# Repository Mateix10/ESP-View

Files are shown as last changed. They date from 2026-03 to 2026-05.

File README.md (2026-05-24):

# ESP-View
This is a music visualiser + DAC that does exactly that - it plays the music through USB, and visualises it.

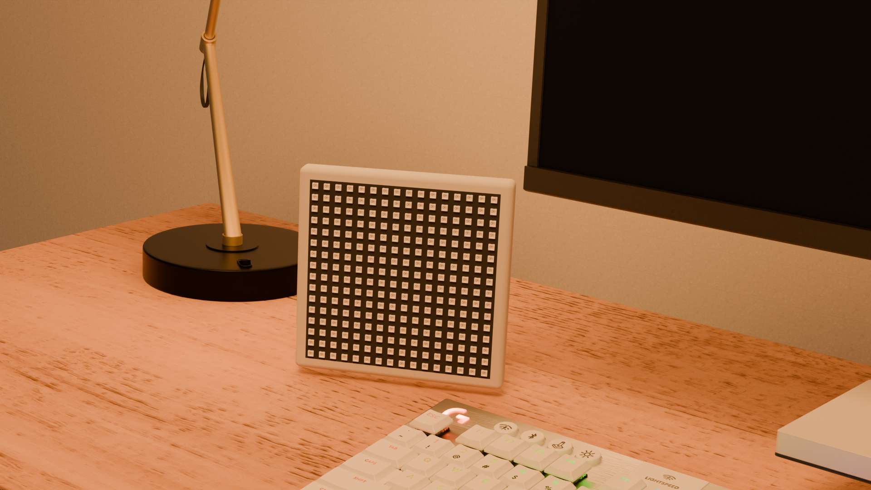
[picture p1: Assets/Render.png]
Render image


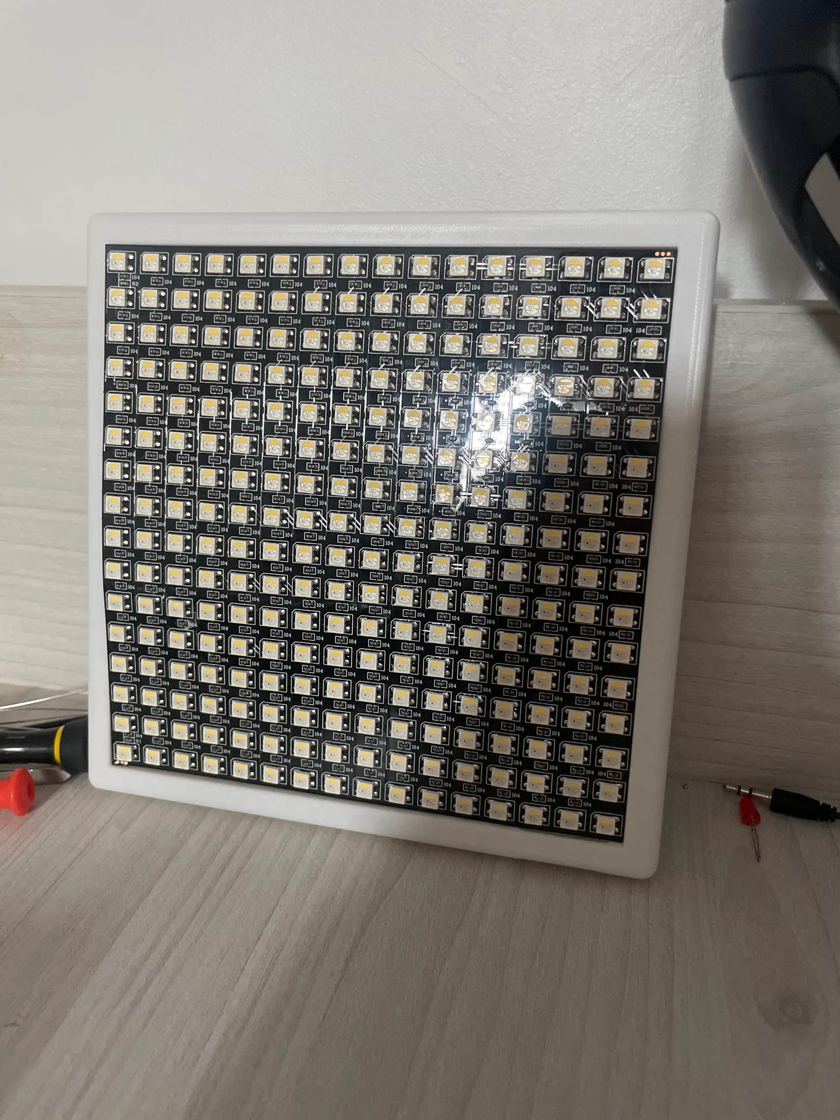
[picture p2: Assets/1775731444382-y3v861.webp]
Build


<sub>Also, a better name will be much appreciated :)</sub>

## PCB
The PCB is designed in kicad.

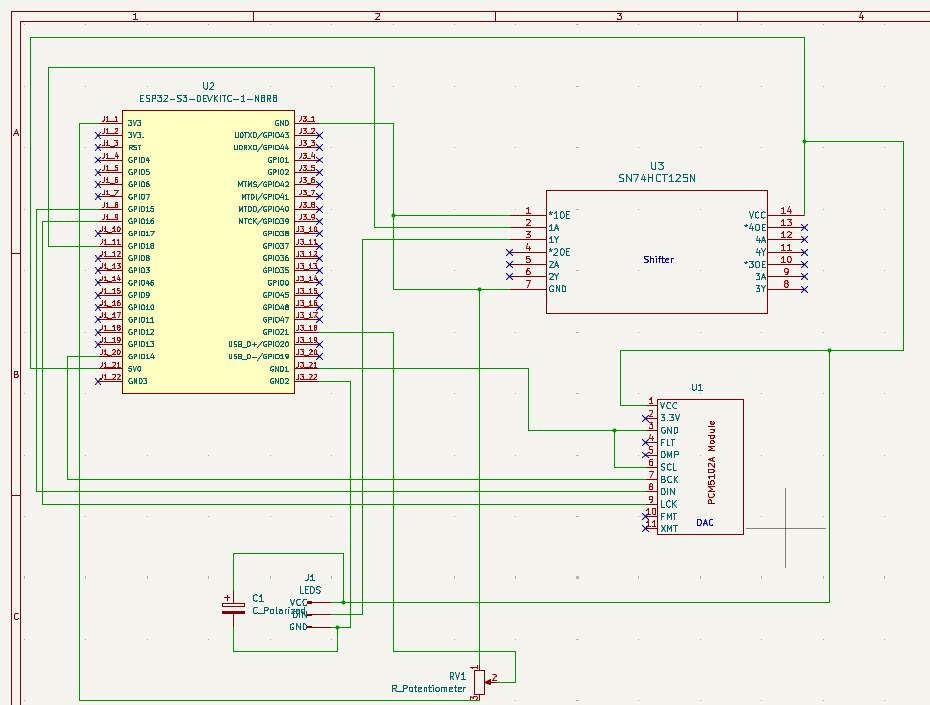
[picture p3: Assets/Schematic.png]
Schematic image


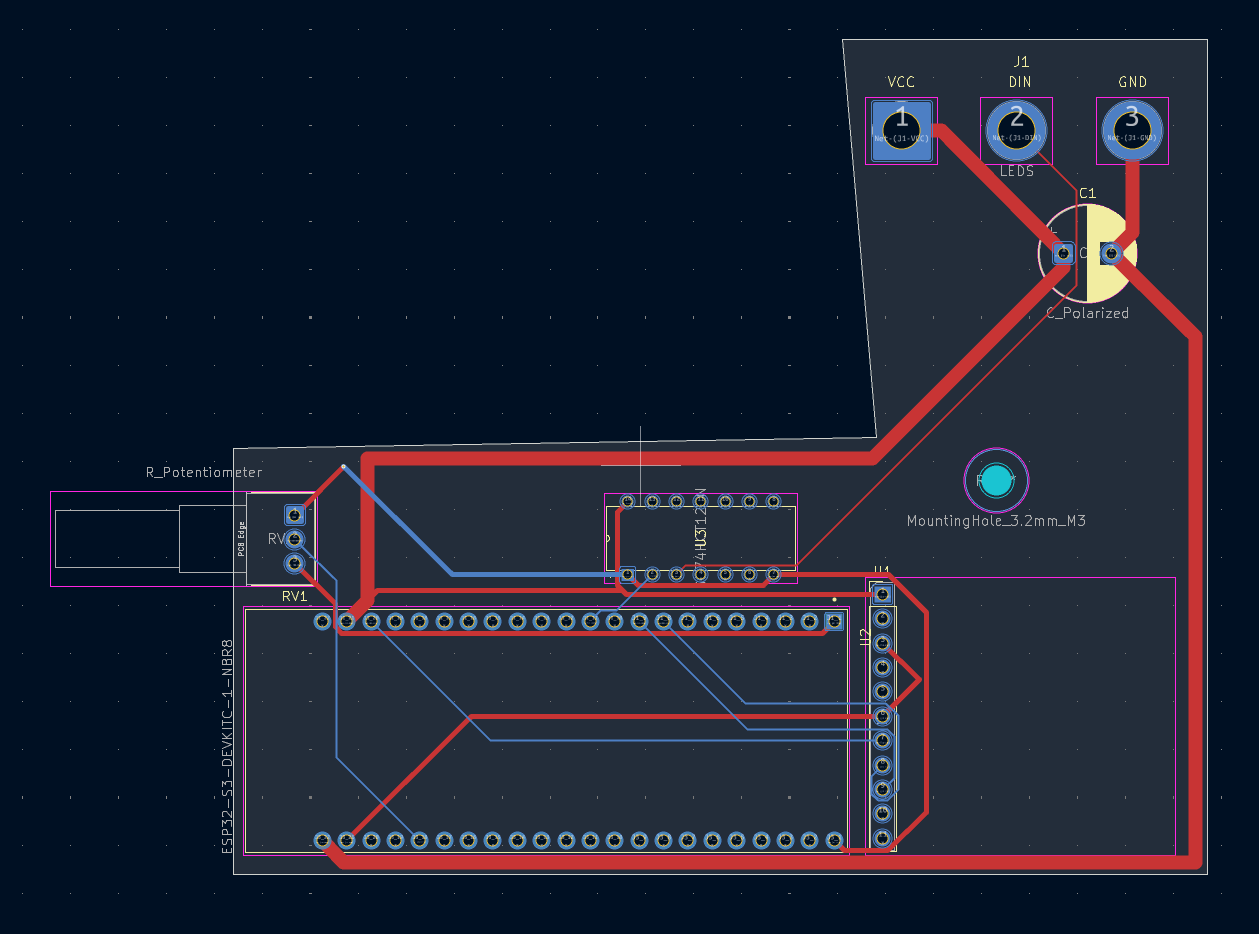
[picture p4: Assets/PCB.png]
PCB image


## Case
The case features a screw and a little groove where the PCB slides.
It has a slick, modern, round design.

Designed in Fusion 360.

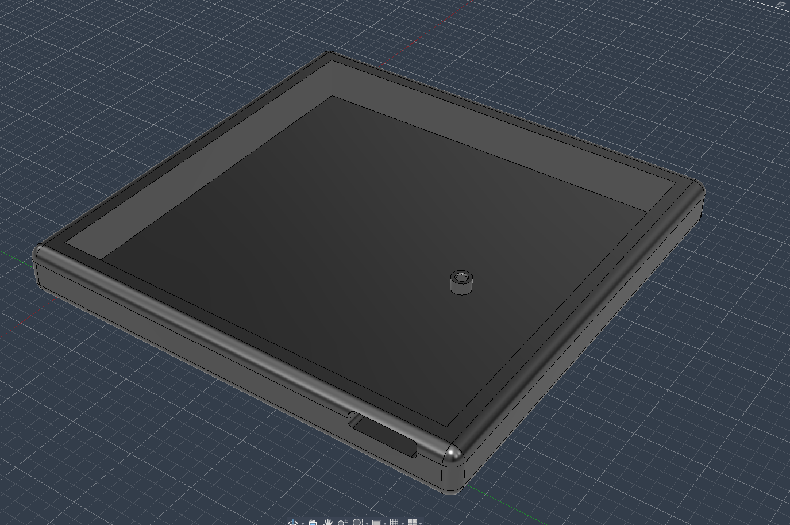
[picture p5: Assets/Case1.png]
Case image


## Firmware 
The whole thing is powered by a ESP32, paired with a PCM5102A DAC.
The firmware is written in Arduino IDE

To interface with the ESP32, you need to install board support in Arduino IDE.
You can do that by going to File -> Preferences -> Additional Board Manager URLs, and add https://espressif.github.io/arduino-esp32/package_esp32_index.json

After that, go to Tools -> Board -> Boards Manager. Search for esp32 and install "esp32" by Espressif.

**WARNING**: Version 3.x is required for proper TinyUSB audio support.

Required libraries:
- NeoPixelBus by Makuna
- arduinoFFT
- TinyUSB (Usually bundled with the EPS32 Arduino Core)

All of these can be installed through the Arduino IDE's library manager.

The Firmware isn't currently tested.

## BOM
| Name | Cost |Link|
|---|---|---|
| 1000uF Electrolytic Capacitor | $0.48 |https://www.optimusdigital.ro/ro/componente-electronice-condensatoare/3004-condensator-electrolitic-de-1000-uf-la-35-v.html|
| LED Matrix | $24.98 |https://www.superlightingled.com/5v-16x16-sk6812-rgbw-led-neopixel-matrix-display-screen-panel-51w-p-6835.html|
| DAC | $22.80 |https://www.optimusdigital.ro/ro/audio-altele/5658-modul-audio-stereo-dac-pcm5102a-cu-interfaa-pcm-32-bii-384-khz.html|
| Level Shifter| $3.19 |https://www.aliexpress.com/item/1005007123530432.html|
|ESP32-S3-DevKitC-1| $18.50 |https://www.aliexpress.com/item/1005003979778978.html|
|PCB|$1.74|-|

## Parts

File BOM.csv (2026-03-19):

Name | Purpose | Cost (USD) | Quantity | Total (USD) | Link | Distribuitor
1000uF Electroltic Capacitor | Clean LED Noise | 0,48 | 1,00 | 0,48 | https://www.optimusdigital.ro/ro/componente-electronice-condensatoare/3004-condensator-electrolitic-de-1000-uf-la-35-v.html | Optimus Digital
LED Matrix | Visualise Sound | 24,98 | 1,00 | 24,98 | https://www.superlightingled.com/5v-16x16-sk6812-rgbw-led-neopixel-matrix-display-screen-panel-51w-p-6835.html | Super lighting led
DAC | Turn digital audio into analog | 22,80 | 1,00 | 22,8 | https://www.optimusdigital.ro/ro/audio-altele/5658-modul-audio-stereo-dac-pcm5102a-cu-interfaa-pcm-32-bii-384-khz.html | Optimus Digital
SN74HCT04AN Level Shifter | Turn 3V3 ESP32 logic into 5V | 3,19 | 1,00 | 3,19 | https://www.aliexpress.com/item/1005007123530432.html | Aliexpress
ESP32-S3-DevKitC-1 | Process visualisation and digital audio | 18,50 | 1,00 | 18,5 | https://www.aliexpress.com/item/1005003979778978.html | Aliexpress
PCB | Connects everything | 1,74 | 1,00 | 1,74 |  | JLCPCB

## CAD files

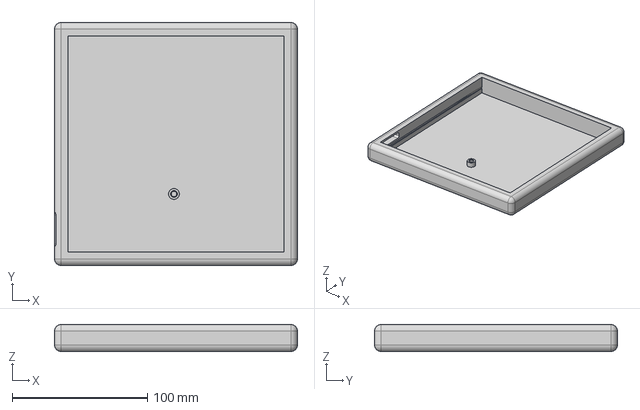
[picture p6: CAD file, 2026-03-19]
CAD/Case.step
180.0 x 180.0 x 20.0 mm

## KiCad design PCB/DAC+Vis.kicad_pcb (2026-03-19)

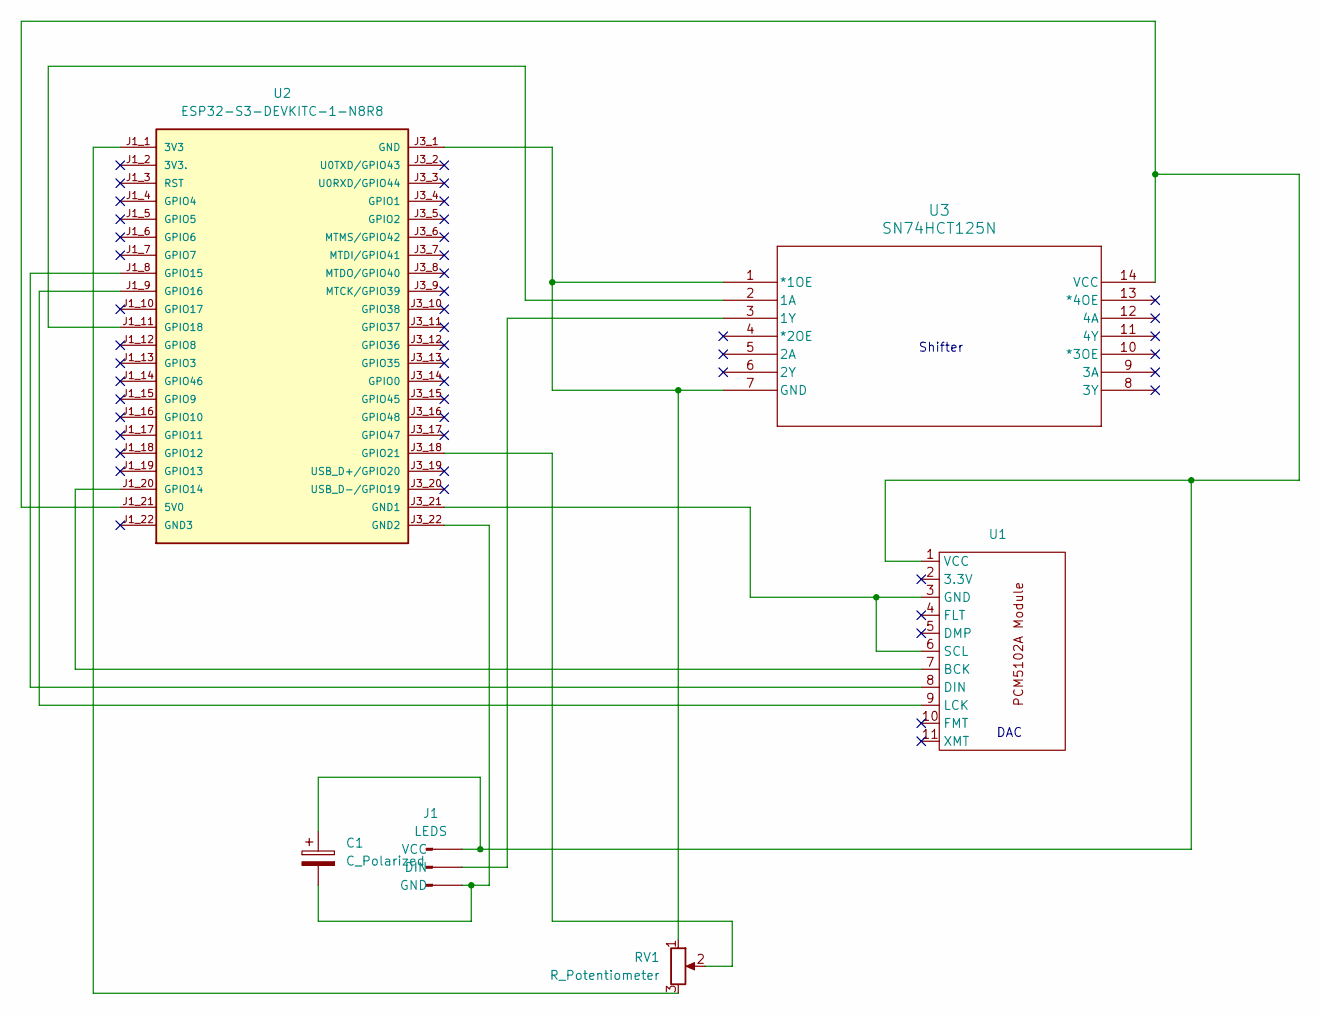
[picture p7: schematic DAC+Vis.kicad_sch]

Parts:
C1: C_Polarized; CP_Radial_D10.0mm_P5.00mm
J1: LEDS; SolderWire-4sqmm_1x03_P12mm_D3mm_OD6mm
RV1: R_Potentiometer; Potentiometer_Alps_RK097_Single_Horizontal
U1: PCM5102A Module
U2: ESP32-S3-DEVKITC-1-N8R8
U3: SN74HCT125N; N14

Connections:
unnamed: J1.2 (DIN), U3.3 (1Y)
unnamed: C1.2, J1.3 (GND), U2.J3_22 (GND2)
unnamed: C1.1, J1.1 (VCC), U1.1 (VCC), U2.J1_21 (5V0), U3.14 (VCC)
unnamed: U1.7 (BCK), U2.J1_20 (GPIO14)
unnamed: U1.8 (DIN), U2.J1_8 (GPIO15)
unnamed: U1.3 (GND), U1.6 (SCL), U2.J3_21 (GND1)
unnamed: U1.9 (LCK), U2.J1_9 (GPIO16)
unnamed: RV1.3, U2.J1_1 (3V3)
unnamed: RV1.1, U2.J3_1 (GND), U3.1 (*1OE), U3.7 (GND)
unnamed: U2.J1_11 (GPIO18), U3.2 (1A)
unnamed: RV1.2, U2.J3_18 (GPIO21)

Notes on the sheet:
Shifter
DAC

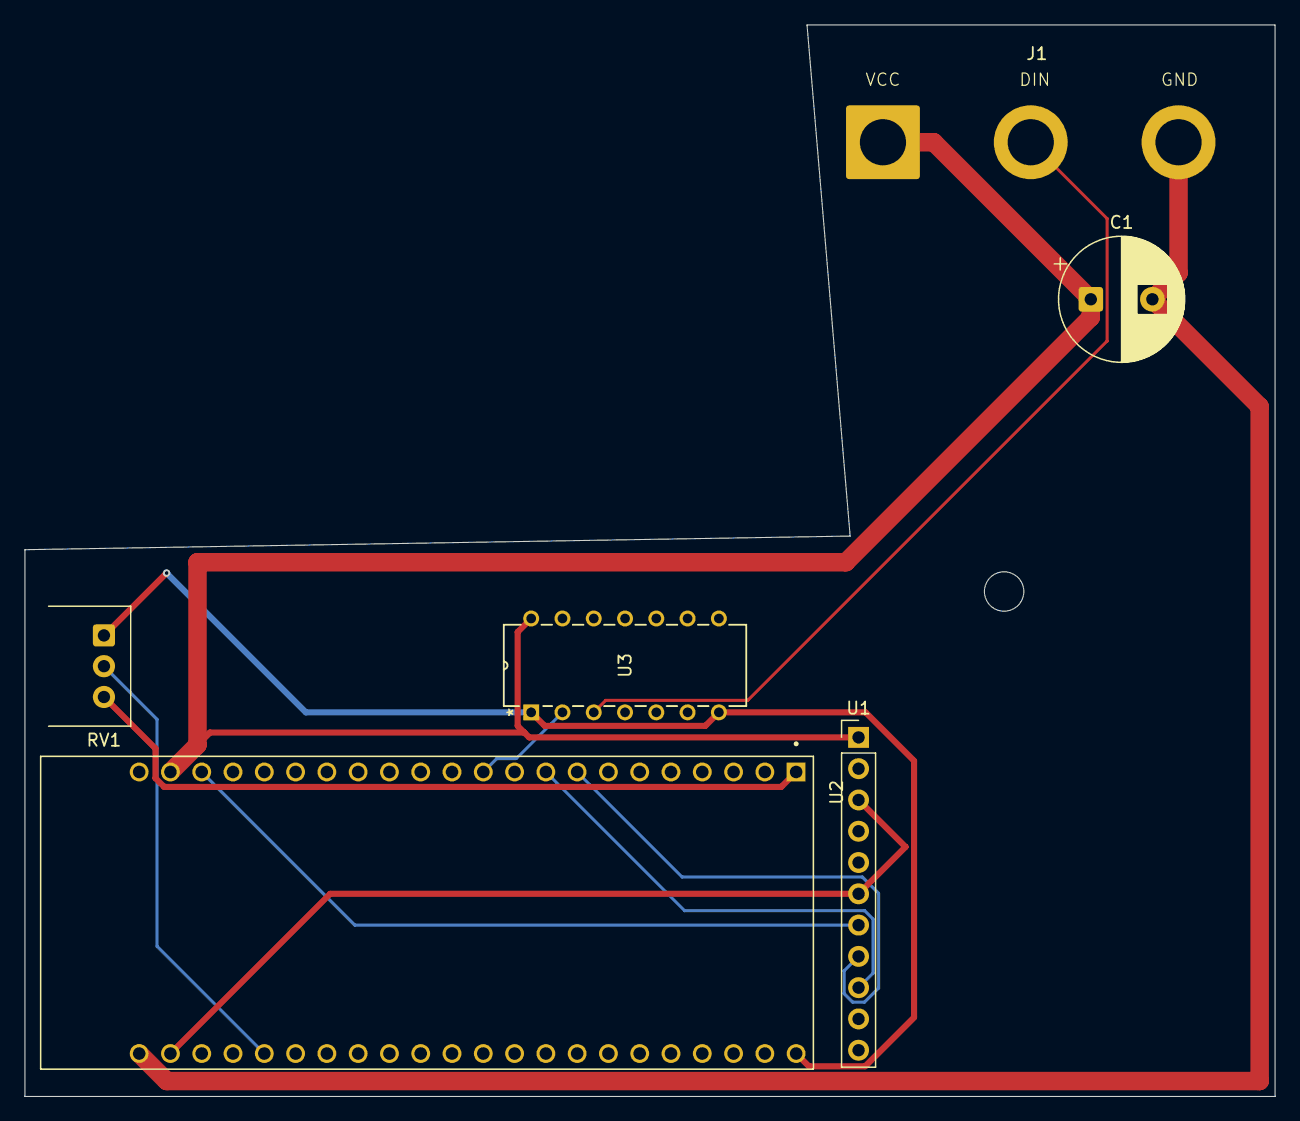
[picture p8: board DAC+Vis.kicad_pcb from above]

Board: 2 copper layers, 101.5 x 87.0 mm, 6 parts (0 on the bottom side), 11 nets.

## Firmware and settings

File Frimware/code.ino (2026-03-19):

#include <Arduino.h>
#include <freertos/FreeRTOS.h>
#include <freertos/task.h>
#include <freertos/queue.h>
#include <driver/i2s.h>
#include <math.h>

#include "USB.h"
#include "tusb.h"
#include <NeoPixelBus.h>
#include <arduinoFFT.h>

// --- Configuration ---
static const uint32_t AUDIO_SAMPLE_RATE    = 48000;
static const uint8_t  AUDIO_CHANNELS       = 2;
static const uint16_t AUDIO_SAMPLE_COUNT   = 48; // 1ms @ 48kHz

static const uint16_t FFT_SAMPLES          = 512;
static const float    FFT_NOISE_FLOOR      = 50.0f;
static const float    FFT_SMOOTHING        = 0.7f;

static const i2s_port_t I2S_DAC_PORT       = I2S_NUM_0;
static const int PIN_I2S_BCK               = 9;
static const int PIN_I2S_LCK               = 11;
static const int PIN_I2S_DOUT              = 16;

static const uint8_t  MATRIX_WIDTH         = 16;
static const uint8_t  MATRIX_HEIGHT        = 16;
static const uint16_t MATRIX_NUM_LEDS      = 256;
static const int      PIN_LED_DATA         = 17;
static const uint8_t  MATRIX_BRIGHTNESS    = 40; // ~15% limit for safety

static const int      PIN_POT              = 21;
static const float    GAIN_MIN             = 0.1f;
static const float    GAIN_MAX             = 5.0f;

static const uint8_t  NUM_BARS             = 16;
static const float    PEAK_FALL_RATE       = 0.15f;
static const uint8_t  PEAK_HOLD_FRAMES     = 12;
static const float    BAR_DECAY_RATE       = 0.85f;

struct DisplayFrame {
    float barHeights[NUM_BARS];
    float peakPositions[NUM_BARS];
    float gain;
};

// --- Globals ---
NeoPixelBus<NeoGrbwFeature, NeoEsp32RmtNSk6812Method> strip(MATRIX_NUM_LEDS, PIN_LED_DATA);

static float fftInput[FFT_SAMPLES];
static float fftOutput[FFT_SAMPLES];
ArduinoFFT<float> FFT(fftInput, fftOutput, FFT_SAMPLES, AUDIO_SAMPLE_RATE);

static QueueHandle_t displayQueue = NULL;
static TaskHandle_t  audioTaskHandle = NULL;
static TaskHandle_t  ledTaskHandle = NULL;

static int16_t audioRingBuffer[FFT_SAMPLES];
static volatile uint16_t ringWritePos = 0;

static float smoothedBars[NUM_BARS] = {0};
static float peakValues[NUM_BARS] = {0};
static uint8_t peakHoldCounters[NUM_BARS] = {0};

static volatile bool usbAudioActive = false;

// --- USB Audio Descriptors ---
enum { ITF_NUM_AUDIO_CONTROL = 0, ITF_NUM_AUDIO_STREAMING, ITF_NUM_TOTAL };

#define TUD_AUDIO_SPEAKER_DESC_LEN (TUD_CONFIG_DESC_LEN + TUD_AUDIO_DESC_IAD_LEN + TUD_AUDIO_DESC_STD_AC_LEN + TUD_AUDIO_DESC_CS_AC_LEN + TUD_AUDIO_DESC_INPUT_TERM_LEN + TUD_AUDIO_DESC_FEATURE_UNIT_TWO_CHANNEL_LEN + TUD_AUDIO_DESC_OUTPUT_TERM_LEN + TUD_AUDIO_DESC_STD_AS_INT_LEN + TUD_AUDIO_DESC_STD_AS_INT_LEN + TUD_AUDIO_DESC_CS_AS_INT_LEN + TUD_AUDIO_DESC_TYPE_I_FORMAT_LEN + TUD_AUDIO_DESC_STD_AS_ISO_EP_LEN + TUD_AUDIO_DESC_CS_AS_ISO_EP_LEN)
#define UAC_ENTITY_SPK_INPUT_TERMINAL 0x01
#define UAC_ENTITY_SPK_FEATURE_UNIT   0x02
#define UAC_ENTITY_SPK_OUTPUT_TERMINAL 0x03
#define EPNUM_AUDIO_OUT 0x01

static const uint8_t desc_configuration[] = {
    TUD_CONFIG_DESCRIPTOR(1, ITF_NUM_TOTAL, 0, TUD_AUDIO_SPEAKER_DESC_LEN, 0x00, 100),
    TUD_AUDIO_DESC_IAD(ITF_NUM_AUDIO_CONTROL, ITF_NUM_TOTAL, 0),
    TUD_AUDIO_DESC_STD_AC(ITF_NUM_AUDIO_CONTROL, 0, 0),
    TUD_AUDIO_DESC_CS_AC(0x0100, TUD_AUDIO_DESC_INPUT_TERM_LEN + TUD_AUDIO_DESC_FEATURE_UNIT_TWO_CHANNEL_LEN + TUD_AUDIO_DESC_OUTPUT_TERM_LEN, 1, ITF_NUM_AUDIO_STREAMING),
    TUD_AUDIO_DESC_INPUT_TERM(UAC_ENTITY_SPK_INPUT_TERMINAL, AUDIO_TERM_TYPE_USB_STREAMING, 0x00, AUDIO_CHANNELS, 0x0003, 0),
    TUD_AUDIO_DESC_FEATURE_UNIT_TWO_CHANNEL(UAC_ENTITY_SPK_FEATURE_UNIT, UAC_ENTITY_SPK_INPUT_TERMINAL, 0x0001, 0x0002, 0x0002, 0),
    TUD_AUDIO_DESC_OUTPUT_TERM(UAC_ENTITY_SPK_OUTPUT_TERMINAL, AUDIO_TERM_TYPE_OUT_GENERIC_SPEAKER, 0x00, UAC_ENTITY_SPK_FEATURE_UNIT, 0),
    TUD_AUDIO_DESC_STD_AS_INT(ITF_NUM_AUDIO_STREAMING, 0x00, 0x00, 0),
    TUD_AUDIO_DESC_STD_AS_INT(ITF_NUM_AUDIO_STREAMING, 0x01, 0x01, 0),
    TUD_AUDIO_DESC_CS_AS_INT(UAC_ENTITY_SPK_INPUT_TERMINAL, 0x01, 0x0001),
    TUD_AUDIO_DESC_TYPE_I_FORMAT(AUDIO_CHANNELS, 2, 16, 0x01, AUDIO_SAMPLE_RATE),
    TUD_AUDIO_DESC_STD_AS_ISO_EP(EPNUM_AUDIO_OUT, (0x01 | 0x10), (AUDIO_SAMPLE_COUNT * 4), 0x01),
    TUD_AUDIO_DESC_CS_AS_ISO_EP(0x01, 0x00, 0x00, 0x0000),
};

static const tusb_desc_device_t desc_device = {
    .bLength = sizeof(tusb_desc_device_t), .bDescriptorType = TUSB_DESC_DEVICE, .bcdUSB = 0x0200,
    .bDeviceClass = 0xEF, .bDeviceSubClass = 0x02, .bDeviceProtocol = 0x01, .bMaxPacketSize0 = 64,
    .idVendor = 0x303A, .idProduct = 0x4002, .bcdDevice = 0x0100,
    .iManufacturer = 0x01, .iProduct = 0x02, .iSerialNumber = 0x03, .bNumConfigurations = 0x01
};

static const char* string_descriptors[] = { (const char[]){0x09, 0x04}, "ESP32-S3", "Spectrum Visualizer", "SV-2026" };

extern "C" {
    void tud_mount_cb(void) {}
    void tud_umount_cb(void) { usbAudioActive = false; }
    void tud_suspend_cb(bool r) { usbAudioActive = false; }
    void tud_resume_cb(void) {}

    bool tud_audio_set_itf_cb(uint8_t rhport, tusb_control_request_t const *p_request) {
        if (tu_u16_low(p_request->wIndex) == ITF_NUM_AUDIO_STREAMING) 
            usbAudioActive = (tu_u16_low(p_request->wValue) == 1);
        return true;
    }

    bool tud_audio_set_itf_close_EP_cb(uint8_t rhport, tusb_control_request_t const *p_request) { return true; }

    bool tud_audio_rx_done_pre_read_cb(uint8_t rhport, uint16_t n_bytes, uint8_t f_id, uint8_t ep, uint8_t alt) {
        if (n_bytes == 0) return true;
        static int16_t buf[AUDIO_SAMPLE_COUNT * 2];
        uint16_t bytes_read = tud_audio_read(buf, n_bytes);
        
        size_t written = 0;
        i2s_write(I2S_DAC_PORT, buf, bytes_read, &written, 0);
        
        uint16_t frames = bytes_read / 4;
        for (uint16_t i = 0; i < frames; i++) {
            audioRingBuffer[ringWritePos] = (int16_t)(((int32_t)buf[i*2] + buf[i*2+1]) / 2);
            ringWritePos = (ringWritePos + 1) % FFT_SAMPLES;
        }
        return true;
    }

    uint8_t const* tud_descriptor_device_cb(void) { return (uint8_t const*)&desc_device; }
    uint8_t const* tud_descriptor_configuration_cb(uint8_t index) { return desc_configuration; }
    uint16_t const* tud_descriptor_string_cb(uint8_t index, uint16_t langid) {
        static uint16_t _desc_str[33];
        if (index == 0) { memcpy(&_desc_str[1], string_descriptors[0], 2); _desc_str[0] = (TUSB_DESC_STRING << 8) | 4; return _desc_str; }
        const char *str = string_descriptors[index];
        uint8_t len = strlen(str);
        if (len > 31) len = 31;
        for (uint8_t i = 0; i < len; i++) _desc_str[1 + i] = str[i];
        _desc_str[0] = (TUSB_DESC_STRING << 8) | (2 * len + 2);
        return _desc_str;
    }
}

// --- Logic ---
void initI2SDAC() {
    i2s_config_t cfg = {
        .mode = (i2s_mode_t)(I2S_MODE_MASTER | I2S_MODE_TX),
        .sample_rate = AUDIO_SAMPLE_RATE,
        .bits_per_sample = I2S_BITS_PER_SAMPLE_16BIT,
        .channel_format = I2S_CHANNEL_FMT_RIGHT_LEFT,
        .communication_format = I2S_COMM_FORMAT_STAND_I2S,
        .intr_alloc_flags = ESP_INTR_FLAG_LEVEL1,
        .dma_buf_count = 8, .dma_buf_len = 256, .use_apll = true, .tx_desc_auto_clear = true
    };
    i2s_pin_config_t pins = { .bck_io_num = PIN_I2S_BCK, .ws_io_num = PIN_I2S_LCK, .data_out_num = PIN_I2S_DOUT, .data_in_num = -1 };
    i2s_driver_install(I2S_DAC_PORT, &cfg, 0, NULL);
    i2s_set_pin(I2S_DAC_PORT, &pins);
}

int16_t matrixMap(uint8_t x, uint8_t y) {
    if (x >= MATRIX_WIDTH || y >= MATRIX_HEIGHT) return -1;
    return (x % 2 == 0) ? (x * MATRIX_HEIGHT + y) : (x * MATRIX_HEIGHT + (MATRIX_HEIGHT - 1 - y));
}

struct BinRange { uint16_t start; uint16_t end; float weight; } barBins[NUM_BARS];

void calculateBinRanges() {
    float hzPerBin = (float)AUDIO_SAMPLE_RATE / FFT_SAMPLES;
    for (int i = 0; i < NUM_BARS; i++) {
        float low = 80.0f * powf(16000.0f / 80.0f, (float)i / NUM_BARS);
        float high = 80.0f * powf(16000.0f / 80.0f, (float)(i + 1) / NUM_BARS);
        barBins[i].start = max(1, (int)(low / hzPerBin));
        barBins[i].end = max((int)barBins[i].start, (int)(high / hzPerBin));
        barBins[i].weight = 1.0f / sqrtf(barBins[i].end - barBins[i].start + 1);
    }
}

RgbwColor getBarColor(uint8_t y, float bright) {
    float ratio = (float)y / MATRIX_HEIGHT;
    uint8_t r = (ratio < 0.5f) ? (uint8_t)(510 * ratio) : 255;
    uint8_t g = (ratio < 0.5f) ? 255 : (uint8_t)(255 - 510 * (ratio - 0.5f));
    return RgbwColor((uint8_t)(r * bright), (uint8_t)(g * bright), 0, 0);
}

void audioFFTTask(void *p) {
    static float hann[FFT_SAMPLES];
    for (int i = 0; i < FFT_SAMPLES; i++) hann[i] = 0.5f * (1.0f - cosf(2.0f * PI * i / (FFT_SAMPLES - 1)));
    
    TickType_t last = xTaskGetTickCount();
    while (1) {
        tud_task();
        if ((xTaskGetTickCount() - last) >= pdMS_TO_TICKS(16)) {
            last = xTaskGetTickCount();
            float gain = (analogRead(PIN_POT) / 4095.0f) * (GAIN_MAX - GAIN_MIN) + GAIN_MIN;
            DisplayFrame frame;
            frame.gain = gain;

            if (usbAudioActive) {
                uint16_t pos = ringWritePos;
                for (int i = 0; i < FFT_SAMPLES; i++) {
                    fftInput[i] = (float)audioRingBuffer[(pos + i) % FFT_SAMPLES] * hann[i];
                    fftOutput[i] = 0;
                }
                FFT.compute(FFTDirection::Forward);
                FFT.complexToMagnitude();

                for (int i = 0; i < NUM_BARS; i++) {
                    float mag = 0;
                    for (int b = barBins[i].start; b <= barBins[i].end; b++) mag += fftInput[b];
                    mag *= barBins[i].weight * gain;
                    float h = (mag > FFT_NOISE_FLOOR) ? log10f(mag) * MATRIX_HEIGHT / 3.0f : 0;
                    h = constrain(h, 0, MATRIX_HEIGHT);
                    
                    smoothedBars[i] = (h >= smoothedBars[i]) ? h : (smoothedBars[i] * BAR_DECAY_RATE);
                    if (smoothedBars[i] >= peakValues[i]) {
                        peakValues[i] = smoothedBars[i];
                        peakHoldCounters[i] = PEAK_HOLD_FRAMES;
                    } else if (peakHoldCounters[i] > 0) {
                        peakHoldCounters[i]--;
                    } else {
                        peakValues[i] = max(0.0f, peakValues[i] - PEAK_FALL_RATE);
                    }
                    frame.barHeights[i] = smoothedBars[i];
                    frame.peakPositions[i] = peakValues[i];
                }
            }
            xQueueOverwrite(displayQueue, &frame);
        }
        vTaskDelay(1);
    }
}

void ledMatrixTask(void *p) {
    strip.Begin();
    strip.Show();
    DisplayFrame frame;
    while (1) {
        if (xQueueReceive(displayQueue, &frame, pdMS_TO_TICKS(50))) {
            strip.ClearTo(RgbwColor(0,0,0,0));
            for (int x = 0; x < NUM_BARS; x++) {
                int h = (int)frame.barHeights[x];
                for (int y = 0; y < h; y++) {
                    int16_t idx = matrixMap(x, y);
                    if (idx >= 0) strip.SetPixelColor(idx, getBarColor(y, 0.8f));
                }
                int16_t pIdx = matrixMap(x, (int)frame.peakPositions[x]);
                if (pIdx >= 0) strip.SetPixelColor(pIdx, RgbwColor(30, 0, 0, 180));
            }
            strip.Show();
        }
        vTaskDelay(pdMS_TO_TICKS(2));
    }
}

void setup() {
    Serial0.begin(115200);
    analogReadResolution(12);
    initI2SDAC();
    calculateBinRanges();
    displayQueue = xQueueCreate(1, sizeof(DisplayFrame));
    USB.begin();
    
    xTaskCreatePinnedToCore(ledMatrixTask, "LED", 4096, NULL, 2, &ledTaskHandle, 0);
    xTaskCreatePinnedToCore(audioFFTTask, "FFT", 8192, NULL, 3, &audioTaskHandle, 1);
}

void loop() { vTaskDelay(pdMS_TO_TICKS(1000)); }

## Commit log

2026-03-18 Enhance README with project details and specifications
    Added detailed description of the project, including case design and hardware specifications.
2026-03-18 Fix typo in README regarding ESP32 description
2026-03-19 Add CAD and PCB files
    [Case.step, DAC+Vis.kicad_pcb, DAC+Vis.kicad_sch]
2026-03-19 Added a render of the device
2026-03-19 Added BOM.csv
    [BOM.csv]
2026-03-19 Add BOM in README
2026-03-19 Add PCB to BOM
    [BOM.csv]
